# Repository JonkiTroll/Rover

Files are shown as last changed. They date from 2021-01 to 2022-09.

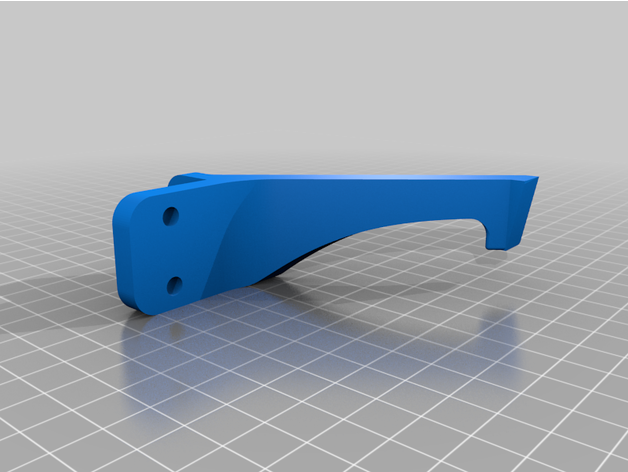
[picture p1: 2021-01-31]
Snow+Tank+from+RCTESTFLIGHT/images/Skid_Leg.png

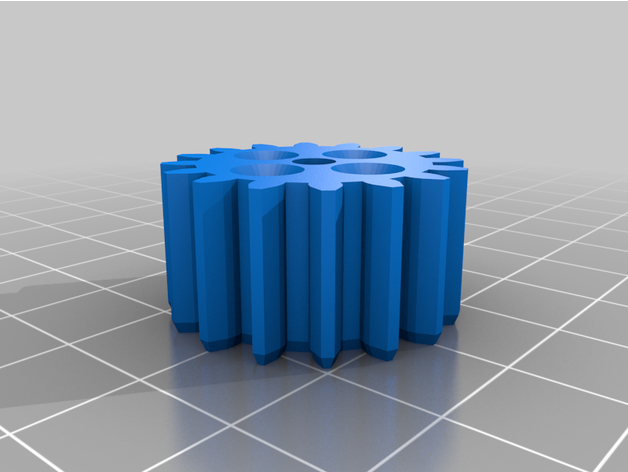
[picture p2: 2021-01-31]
Snow+Tank+from+RCTESTFLIGHT/images/Motor_Gear.png

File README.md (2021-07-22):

# Rover
Implementation of a rc tank. Based on rctestflight's design.

# Requirements
Python 3.8 on server and rover

pyttsx3 python library for RoverTTS.py. For Ubuntu linux, libespeak1 needs to be installed manually (sudo apt install libespeak1).

OpenCv2 for Video_server.py. 

# Utilities
GPS 	GY-NEO6MV2

IMU	Icm20948 (Pid controller)

Camera (Servo)  logitech webcam

Speakers

Temp, gas, barometer, humidity https://www.bosch-sensortec.com/products/environmental-sensors/gas-sensors/bme688/

Neopixels

Battery management (Fuel gauge) https://www.ti.com/product/BQ34110#product-details##description

expansion headers (Servos, analog pins)

Hall Effect sensors x2 (3390Q)

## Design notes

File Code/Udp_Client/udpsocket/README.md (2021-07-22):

# udpsocket

A udp socket created for Raspberry pi 4. UDPClient is the physical code set up on the raspberry and is designed to receive data from the controller.
It connects to an external server.
This project is based on CMake. The IDE used is CLion.

#Stuff to remember:

Uart Endmarkers.

ESC grounding.

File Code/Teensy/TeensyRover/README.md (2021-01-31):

# TeensyRover
A Teensy is used to generate a clean 1kHz signal to control the esc. Low en of the duty cycle is 13%, and high end 24%.
To compile and run the example, platformio is needed (https://docs.platformio.org/en/latest/what-is-platformio.html)

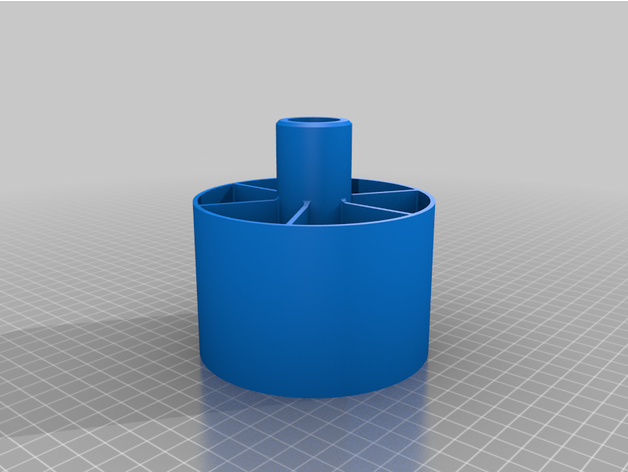
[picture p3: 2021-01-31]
Snow+Tank+from+RCTESTFLIGHT/images/103mm_Idler_Wheel.png

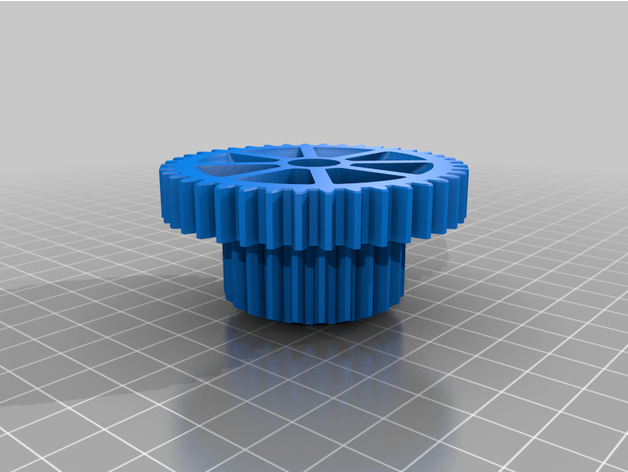
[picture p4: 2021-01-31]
Snow+Tank+from+RCTESTFLIGHT/images/40T_Output.png

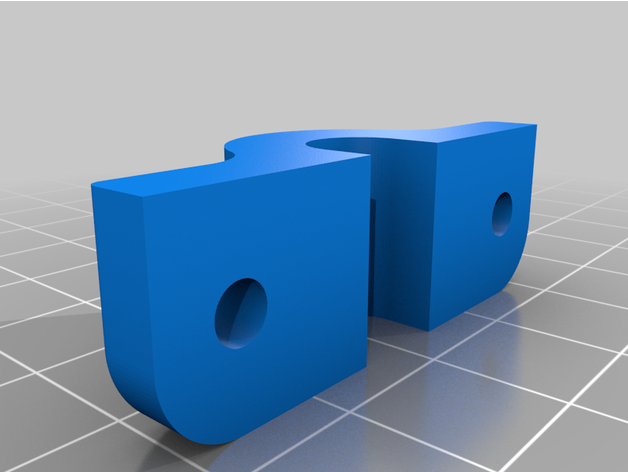
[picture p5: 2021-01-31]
Snow+Tank+from+RCTESTFLIGHT/images/8mm_Axel_Bracket.png

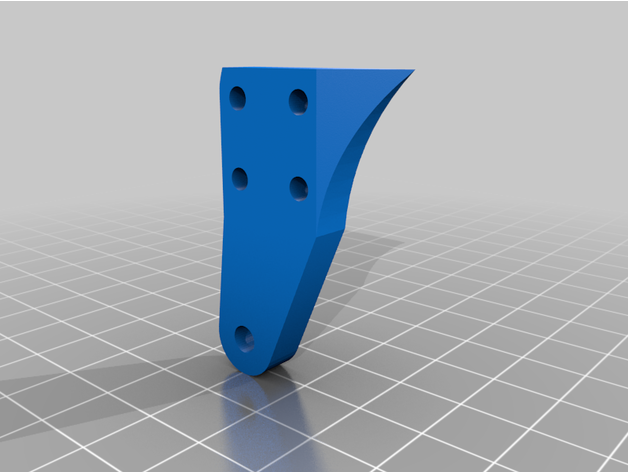
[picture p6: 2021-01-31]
Snow+Tank+from+RCTESTFLIGHT/images/Gearbox_Wrap_around_Plate.png

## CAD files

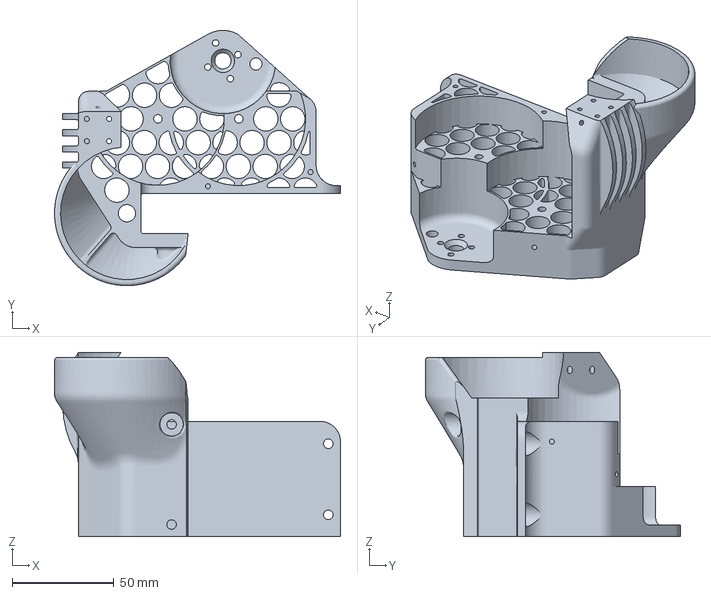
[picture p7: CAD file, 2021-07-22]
Snow+Tank+from+RCTESTFLIGHT/files/56_to_1_housing.3mf
140.7 x 125.6 x 90.8 mm

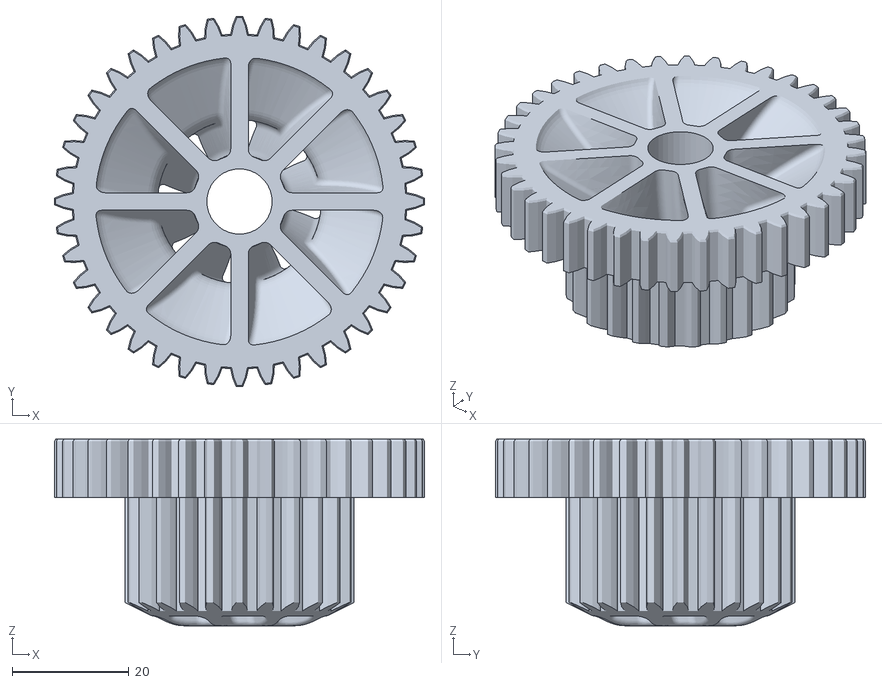
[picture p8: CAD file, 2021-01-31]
Snow+Tank+from+RCTESTFLIGHT/files/40T_Output.STL
63.5 x 63.5 x 32.0

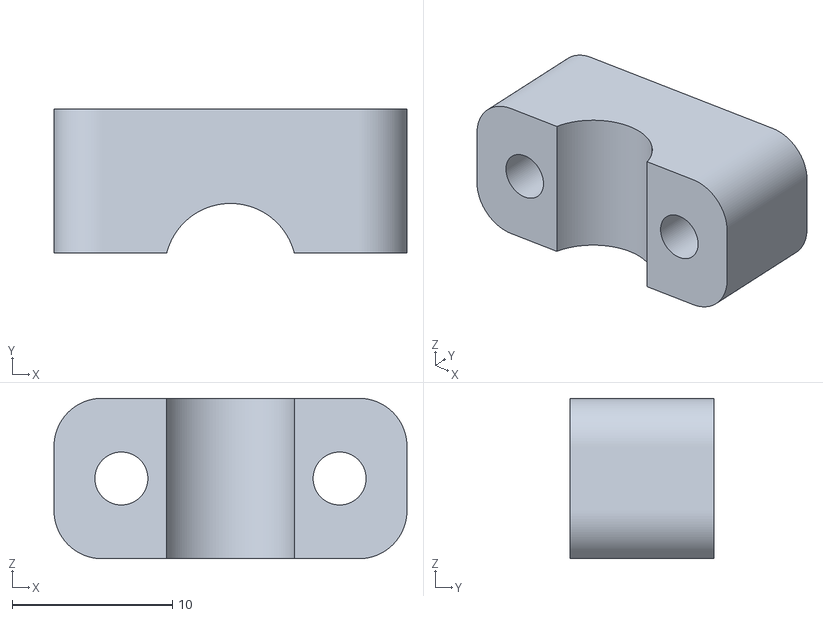
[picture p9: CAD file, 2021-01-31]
Snow+Tank+from+RCTESTFLIGHT/files/8mm_Tube_Clamp.stl
22.0 x 9.00 x 10.0

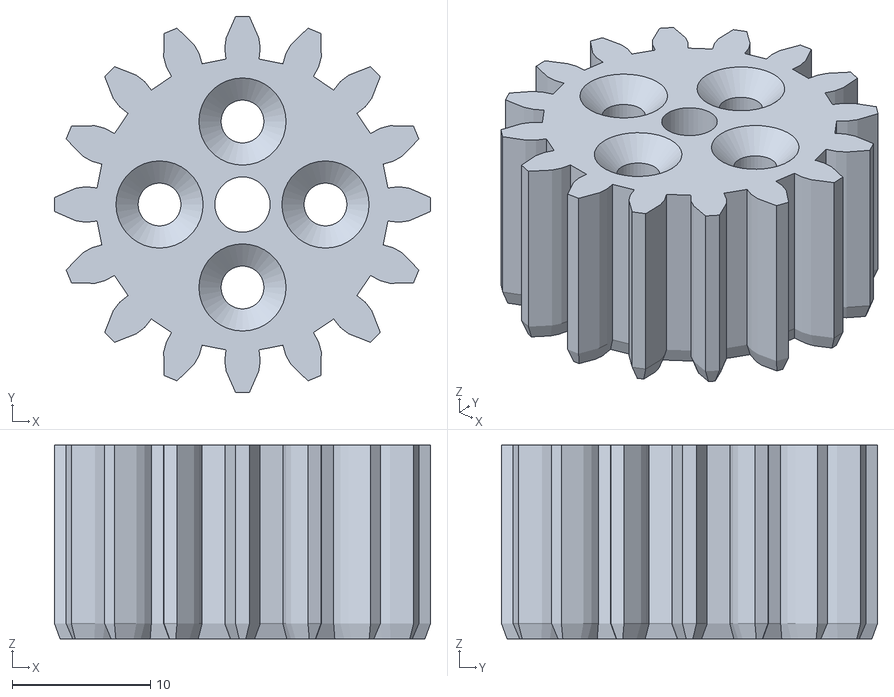
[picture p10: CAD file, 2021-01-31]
Snow+Tank+from+RCTESTFLIGHT/files/Motor_Gear.STL
27.2 x 27.2 x 14.0

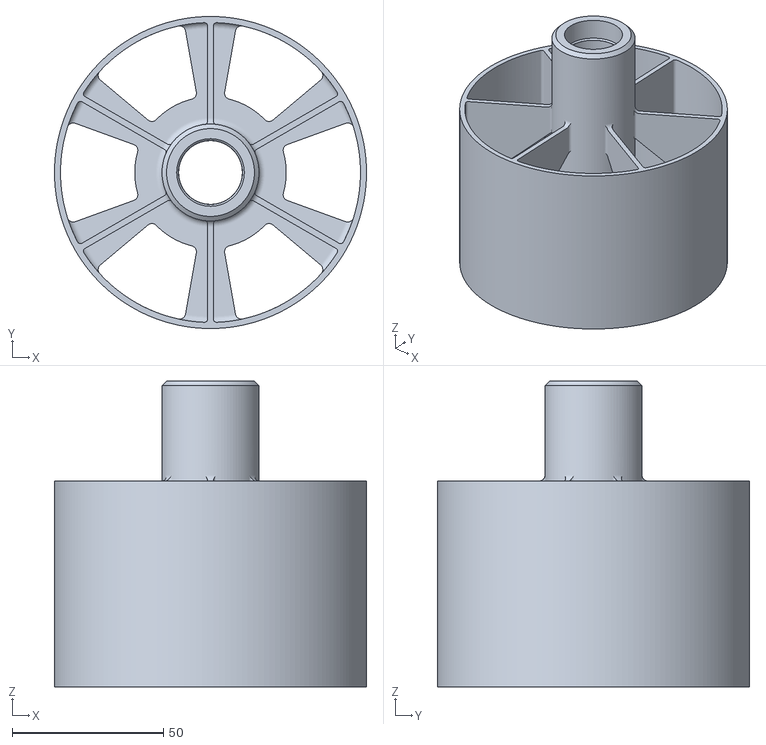
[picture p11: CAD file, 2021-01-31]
Snow+Tank+from+RCTESTFLIGHT/files/103mm_Idler_Wheel.stl
103.0 x 103.0 x 101.0

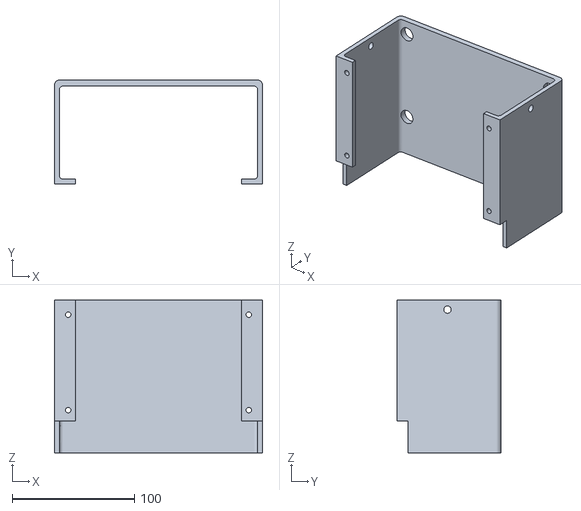
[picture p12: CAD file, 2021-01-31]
Snow+Tank+from+RCTESTFLIGHT/files/Simple_Top_Box.stl
170.0 x 85.0 x 125.0

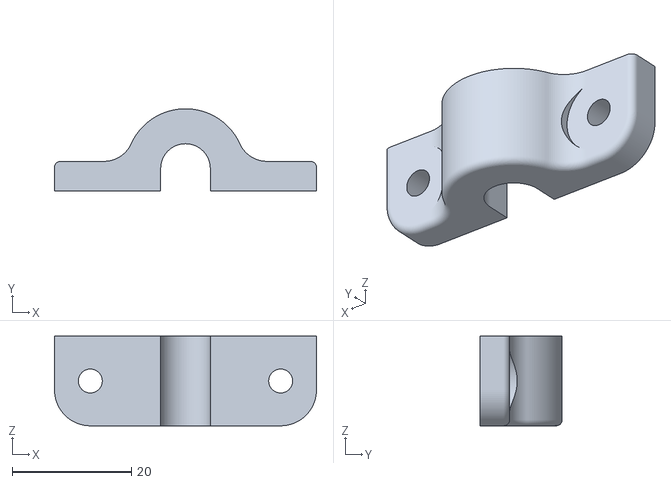
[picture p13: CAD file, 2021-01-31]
Snow+Tank+from+RCTESTFLIGHT/files/8mm_Axel_Bracket.stl
43.9 x 13.8 x 15.0

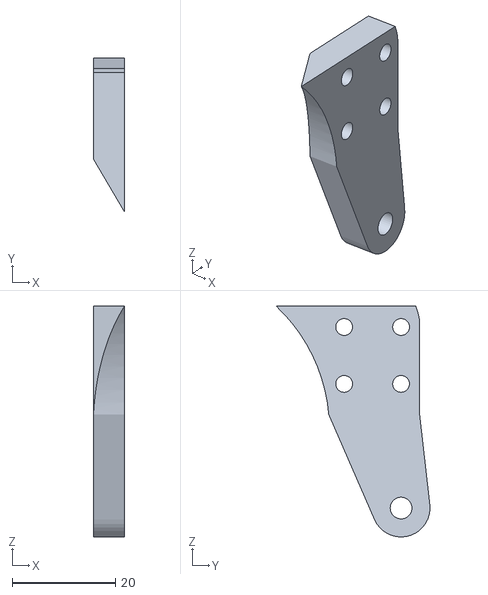
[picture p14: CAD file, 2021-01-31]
Snow+Tank+from+RCTESTFLIGHT/files/Gearbox_Wrap_around_Plate.STL
6.00 x 29.8 x 44.7

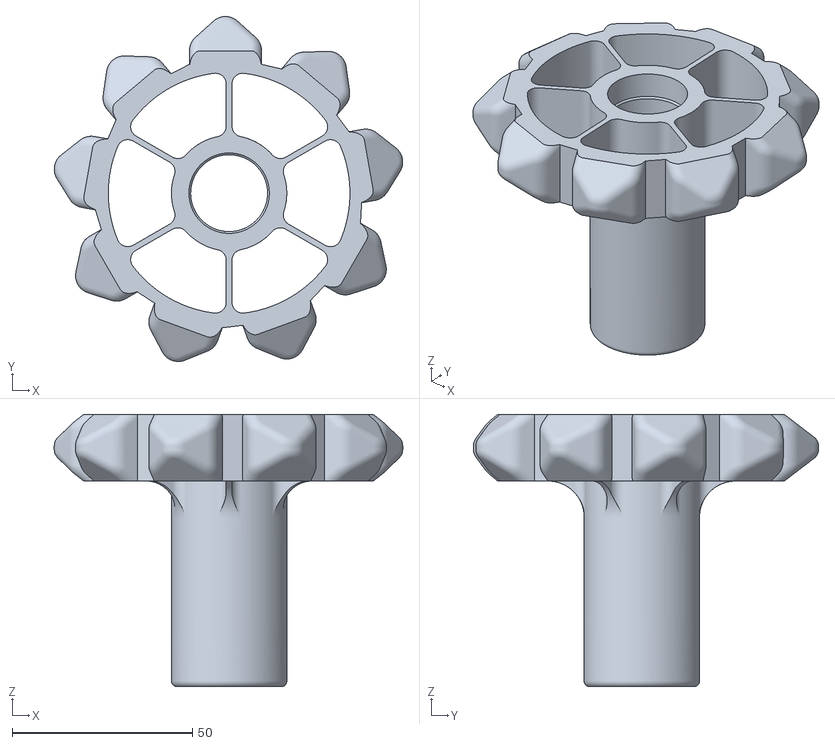
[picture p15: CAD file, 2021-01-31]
Snow+Tank+from+RCTESTFLIGHT/files/Snow_Pully_Rear.stl
96.6 x 95.7 x 75.5

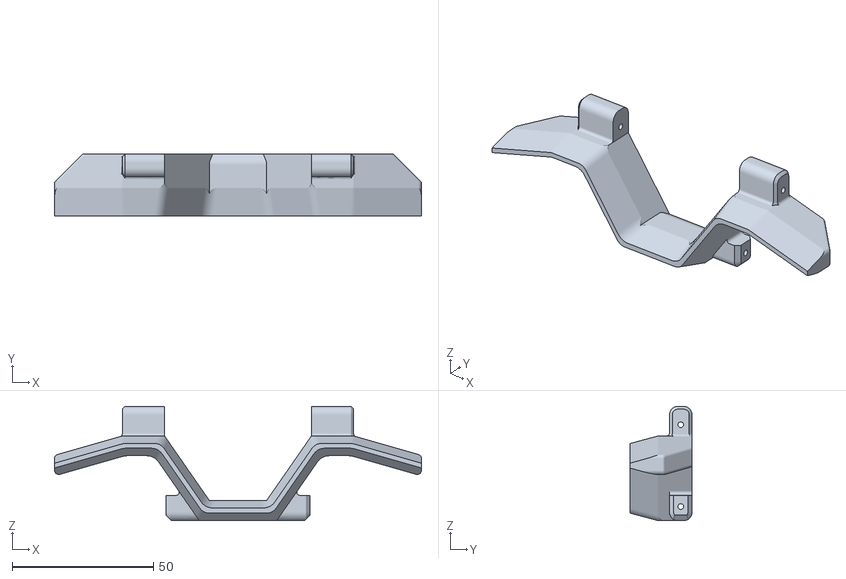
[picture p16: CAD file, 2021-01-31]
Snow+Tank+from+RCTESTFLIGHT/files/Snow_Track.STL
130.0 x 22.0 x 40.5

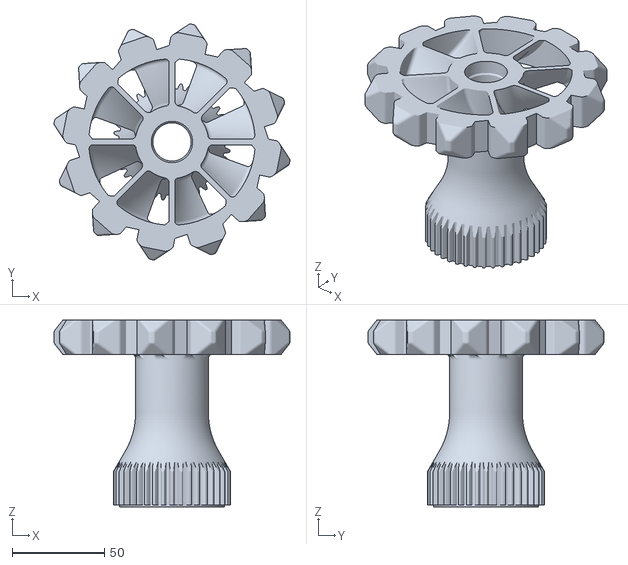
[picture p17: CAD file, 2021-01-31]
Snow+Tank+from+RCTESTFLIGHT/files/Snow_Wheel.stl
127.7 x 127.7 x 101.0

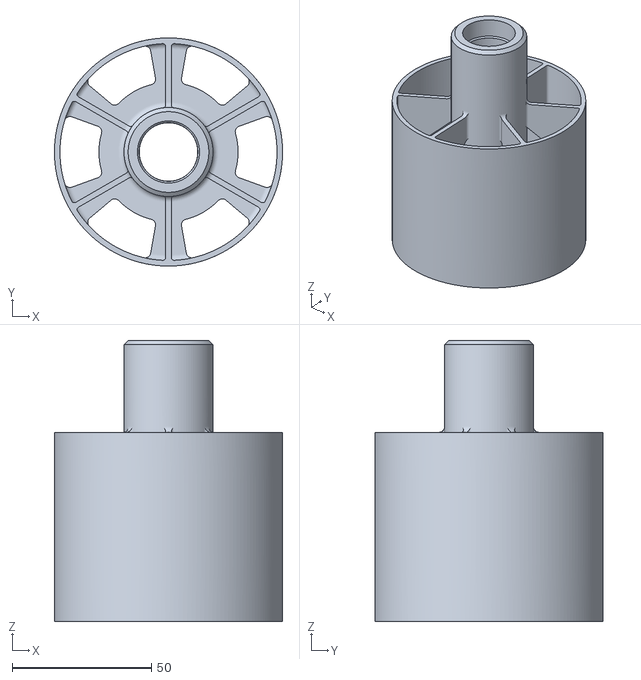
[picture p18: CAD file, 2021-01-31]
Snow+Tank+from+RCTESTFLIGHT/files/82mm_Idler_Wheel.stl
82.0 x 82.0 x 101.0

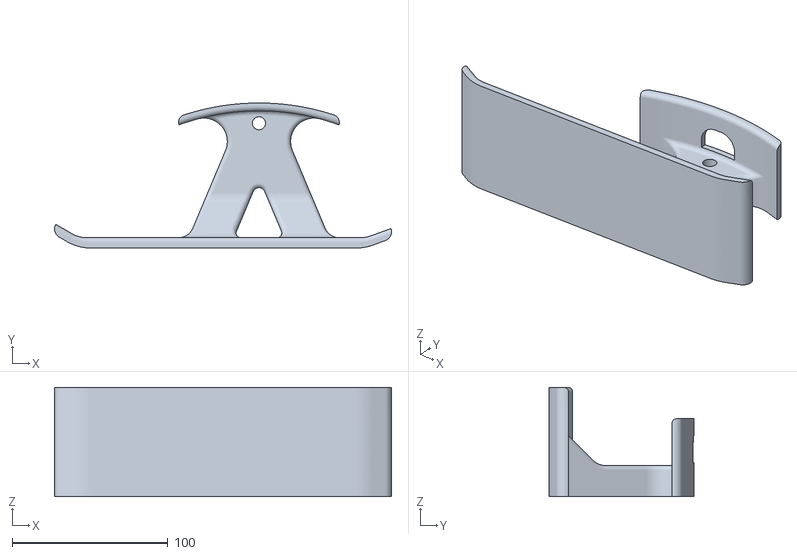
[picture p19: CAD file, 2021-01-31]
Snow+Tank+from+RCTESTFLIGHT/files/Skid.stl
216.1 x 93.0 x 70.0

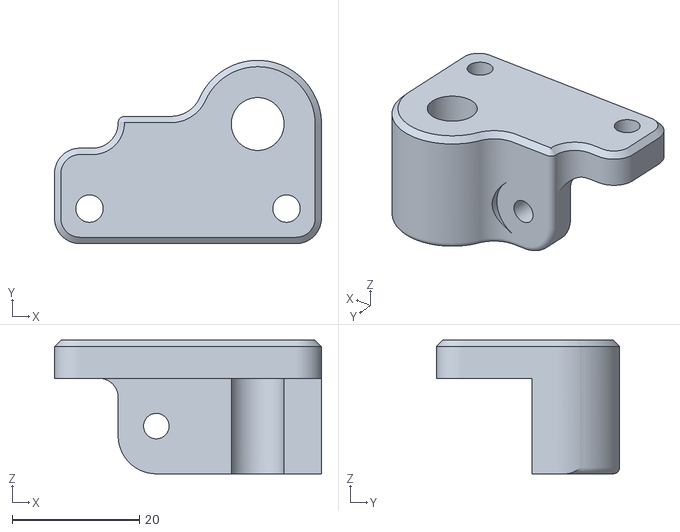
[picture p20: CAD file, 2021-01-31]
Snow+Tank+from+RCTESTFLIGHT/files/Corner_Axel_Holder_for_skids_only.stl
42.0 x 28.8 x 21.0

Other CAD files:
Snow+Tank+from+RCTESTFLIGHT/files/Skid_Leg.stl
Snow+Tank+from+RCTESTFLIGHT/files/Rear_Axel_Holder.STL
Snow+Tank+from+RCTESTFLIGHT/files/40T.STL
PCB/RaspberryPiHat_V2/TXB0108DQSR/Allegro/txb0108dqsr.psm
PCB/RaspberryPiHat_V2/TXB0108DQSR/DEHDL/txb0108dqsr/chips/chips.prt
Snow+Tank+from+RCTESTFLIGHT/files/56_to_1_housing.STL

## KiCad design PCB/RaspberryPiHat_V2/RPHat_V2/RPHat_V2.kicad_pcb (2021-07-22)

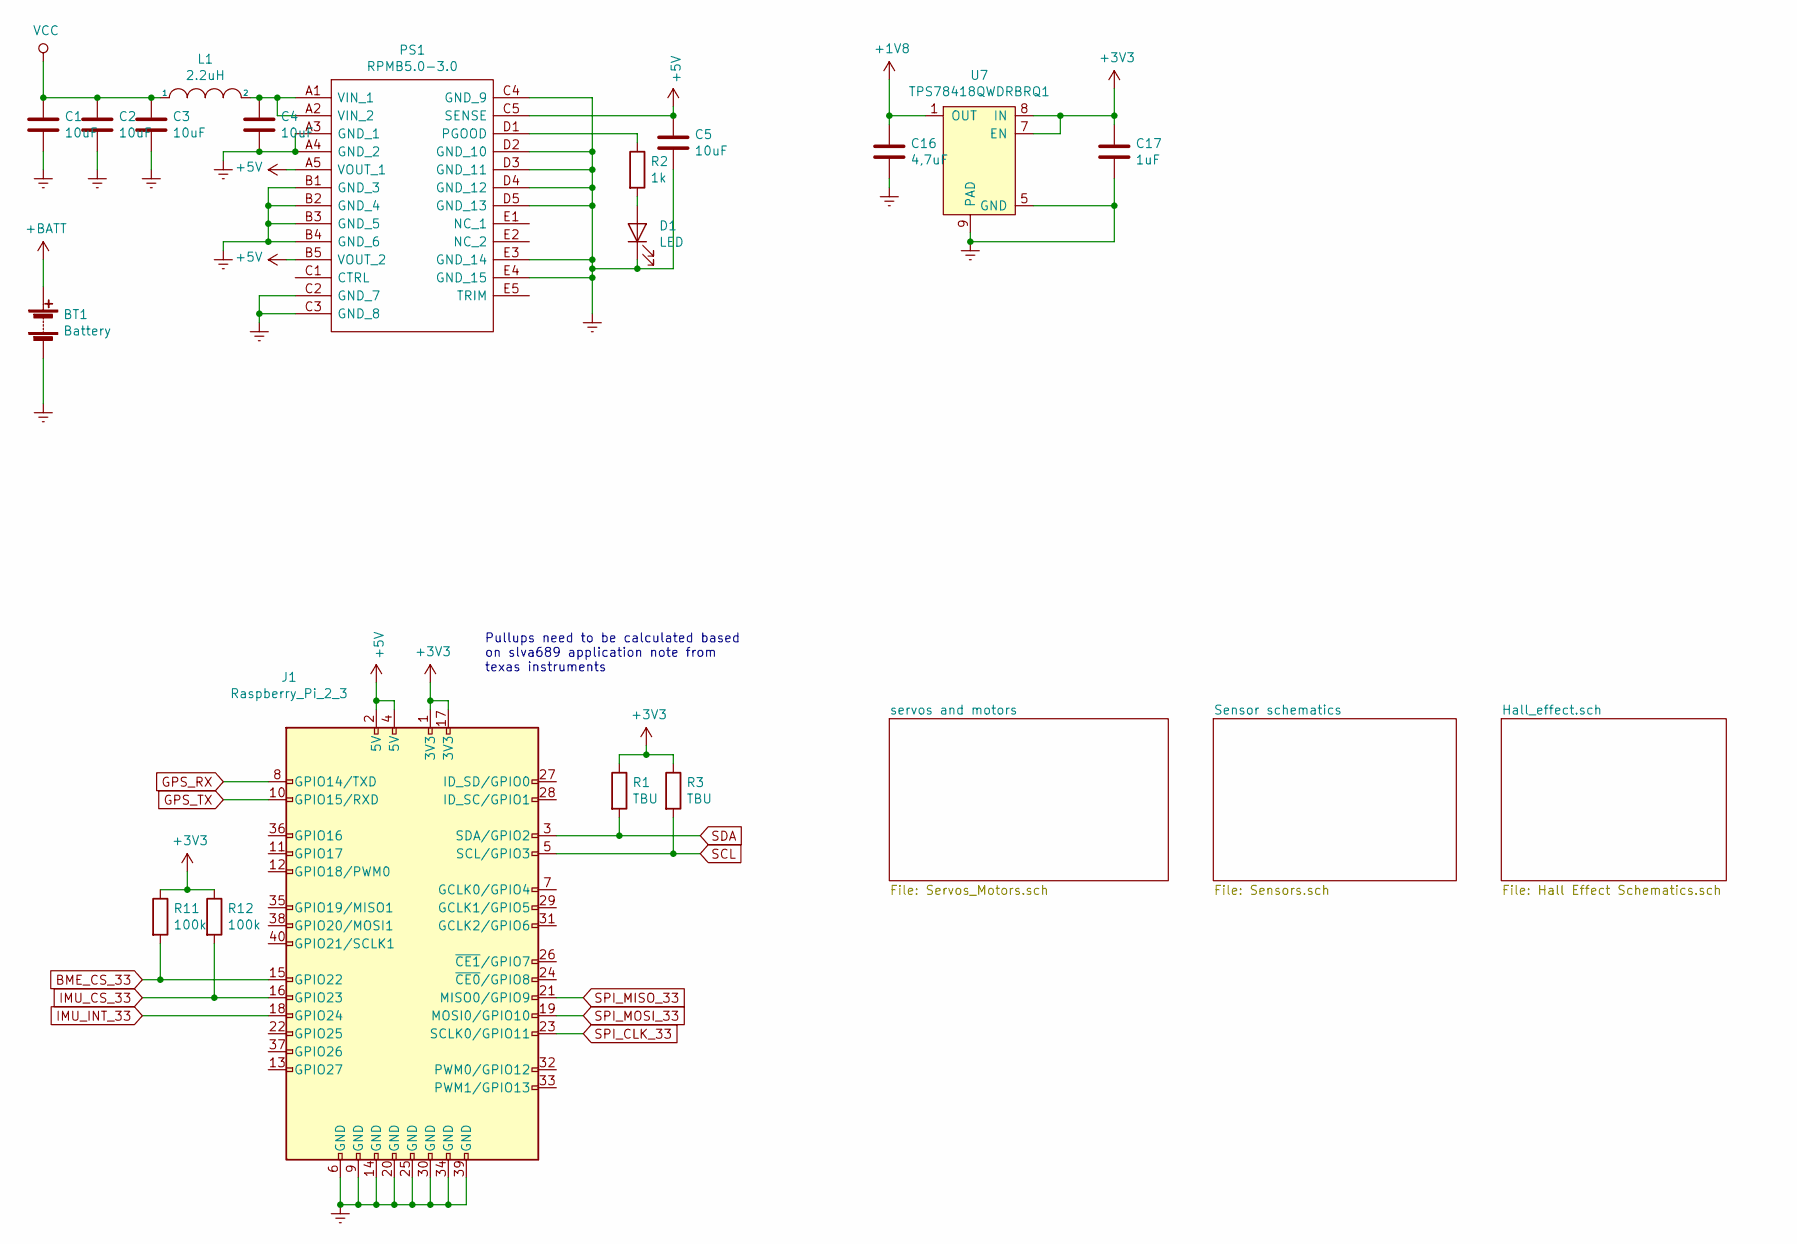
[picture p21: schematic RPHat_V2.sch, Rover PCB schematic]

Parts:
BT1: Battery; AMASS_XT60-M_1x02_P7.20mm_Vertical
C1, C2, C3, C4, C5: 10uF; C_1210_3225Metric_Pad1.33x2.70mm_HandSolder
C16: 4,7uF; C_0402_1005Metric_Pad0.74x0.62mm_HandSolder
C17: 1uF; C_0402_1005Metric_Pad0.74x0.62mm_HandSolder
D1: LED; R_0603_1608Metric_Pad0.98x0.95mm_HandSolder
J1: Raspberry_Pi_2_3; PinHeader_2x20_P2.54mm_Vertical
L1: 2.2uH; L_1008_2520Metric_Pad1.43x2.20mm_HandSolder
PS1: RPMB5.0-3.0; RPMB5030; Manufacturer_Part_Number RPMB5.0-3.0; Mouser Part Number 919-RPMB5.0-3.0
R1, R3: TBU; R_0603_1608Metric_Pad0.98x0.95mm_HandSolder
R2: 1k; R_0603_1608Metric_Pad0.98x0.95mm_HandSolder
R11, R12: 100k; R_0402_1005Metric_Pad0.72x0.64mm_HandSolder
U7: TPS78418QWDRBRQ1; Texas_S-PVSON-N8_ThermalVias

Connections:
+1V8: C16.1, U7.1 (OUT); also elsewhere on the board
+5V: C5.1, J1.2 (5V), J1.4 (5V), PS1.A5 (VOUT_1), PS1.B5 (VOUT_2), PS1.C5 (SENSE); also elsewhere on the board
+BATT: BT1.1 (+); also elsewhere on the board
BME_CS_33: J1.15 (GPIO22), R11.2; also elsewhere on the board
GNDREF: BT1.2 (-), C1.2, C2.2, C3.2, C4.2, C5.2, C16.2, C17.2, D1.1 (K), J1.6 (GND), J1.9 (GND), J1.14 (GND), J1.20 (GND), J1.25 (GND), J1.30 (GND), J1.34 (GND), J1.39 (GND), PS1.A3 (GND_1), PS1.A4 (GND_2), PS1.B1 (GND_3), PS1.B2 (GND_4), PS1.B3 (GND_5), PS1.B4 (GND_6), PS1.C2 (GND_7), PS1.C3 (GND_8), PS1.C4 (GND_9), PS1.D2 (GND_10), PS1.D3 (GND_11), PS1.D4 (GND_12), PS1.D5 (GND_13), PS1.E3 (GND_14), PS1.E4 (GND_15), U7.5 (GND), U7.9 (PAD); also elsewhere on the board
GPS_RX: J1.8 (GPIO14/TXD); also elsewhere on the board
GPS_TX: J1.10 (GPIO15/RXD); also elsewhere on the board
IMU_CS_33: J1.16 (GPIO23), R12.2; also elsewhere on the board
IMU_INT_33: J1.18 (GPIO24); also elsewhere on the board
unnamed: C4.1, L1.2, PS1.A1 (VIN_1), PS1.A2 (VIN_2)
unnamed: D1.2 (A), R2.2
unnamed: PS1.D1 (PGOOD), R2.1
SCL: J1.5 (SCL/GPIO3), R3.2; also elsewhere on the board
SDA: J1.3 (SDA/GPIO2), R1.2; also elsewhere on the board
SPI_CLK_33: J1.23 (SCLK0/GPIO11); also elsewhere on the board
SPI_MISO_33: J1.21 (MISO0/GPIO9); also elsewhere on the board
SPI_MOSI_33: J1.19 (MOSI0/GPIO10); also elsewhere on the board
VCC: C1.1, C2.1, C3.1, L1.1; also elsewhere on the board

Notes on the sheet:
Pullups need to be calculated based on slva689 application note from texas instruments

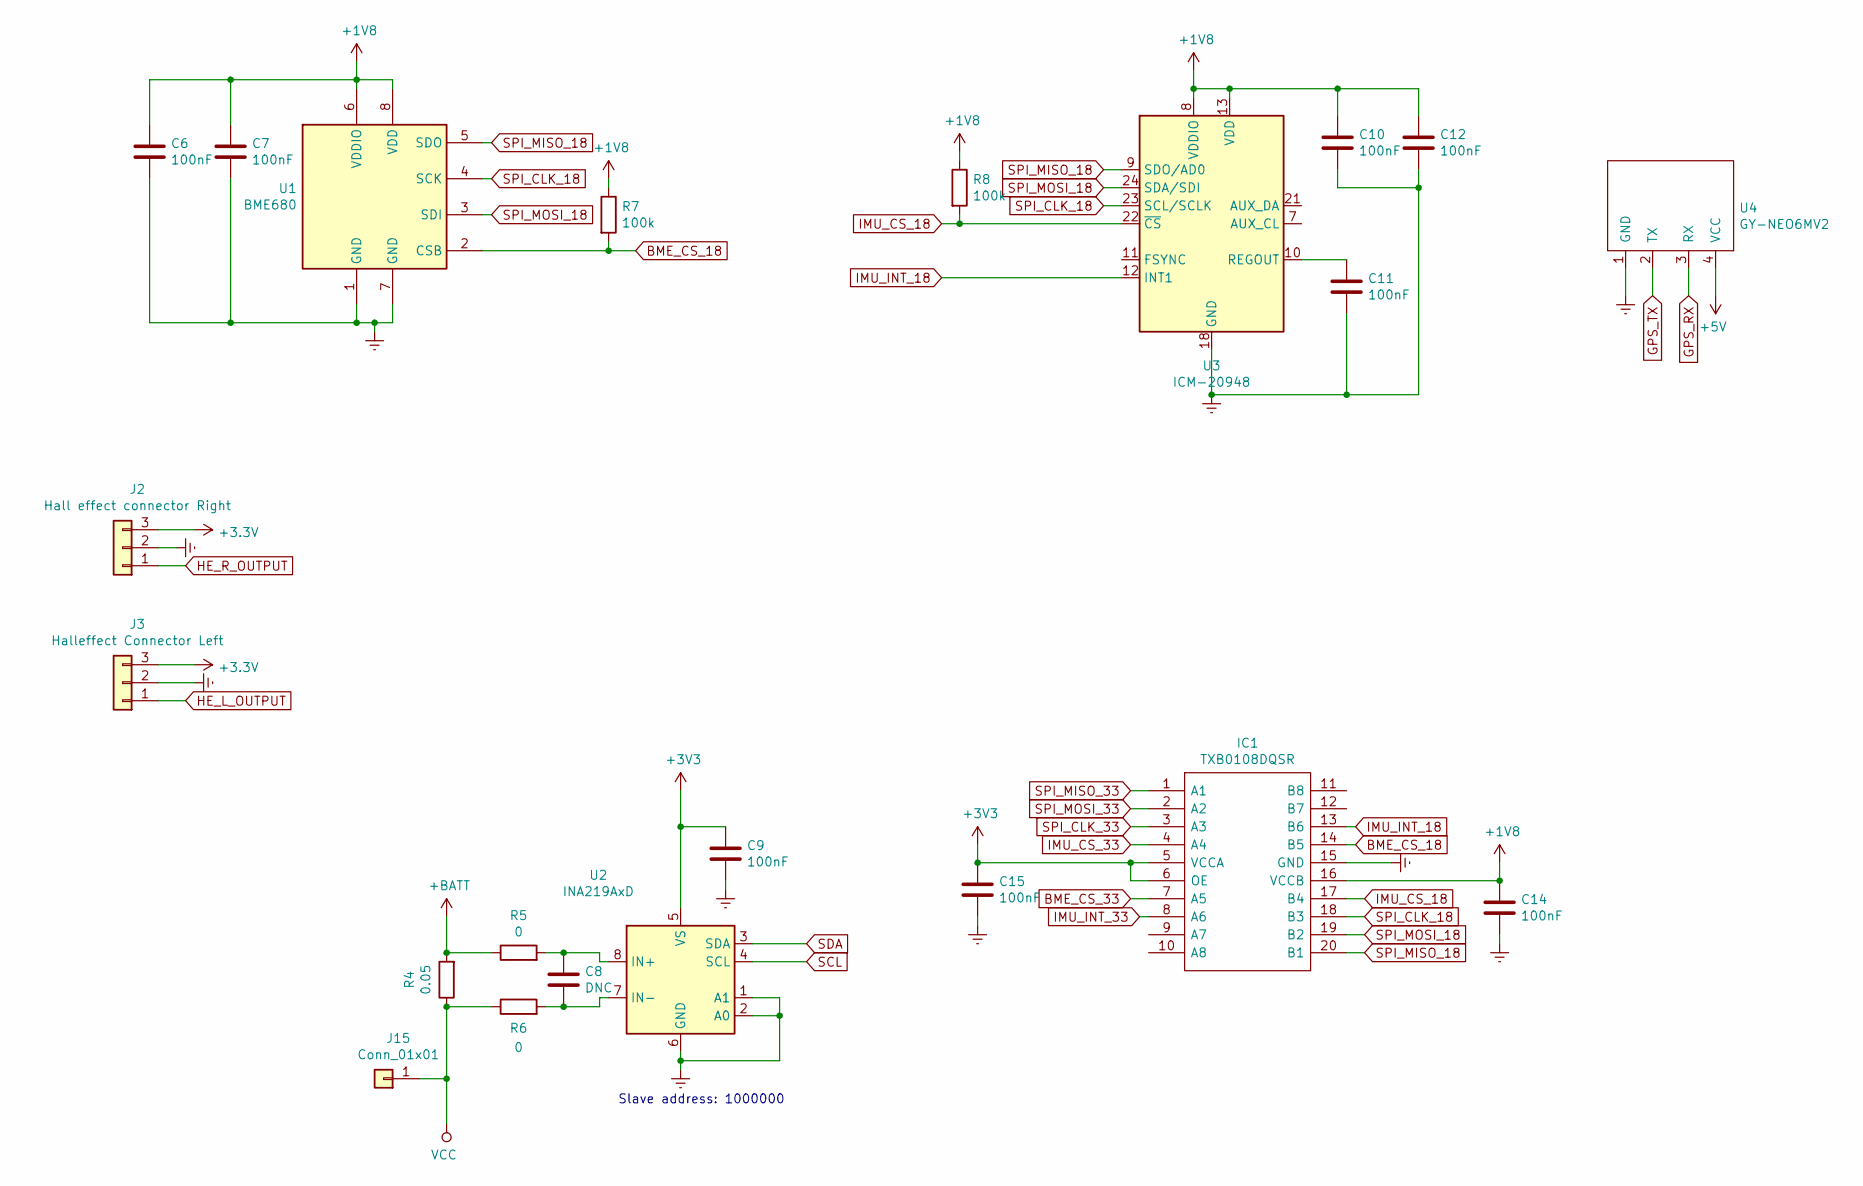
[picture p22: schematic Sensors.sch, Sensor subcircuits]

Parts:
C6, C7, C10, C11, C12, C14, C15: 100nF; C_0402_1005Metric_Pad0.74x0.62mm_HandSolder
C8: DNC; C_0603_1608Metric_Pad1.08x0.95mm_HandSolder
C9: 100nF; C_0603_1608Metric_Pad1.08x0.95mm_HandSolder
IC1: TXB0108DQSR; Manufacturer_Part_Number TXB0108DQSR; Mouser Part Number 595-TXB0108DQSR
J2: Hall effect connector Right; JST_EH_B3B-EH-A_1x03_P2.50mm_Vertical
J3: Halleffect Connector Left; JST_EH_B3B-EH-A_1x03_P2.50mm_Vertical
J15: Conn_01x01; Pin_D1.3mm_L11.0mm
R4: 0.05; CSS2H-3920
R5, R6: 0; R_0603_1608Metric_Pad0.98x0.95mm_HandSolder
R7, R8: 100k; R_0402_1005Metric_Pad0.72x0.64mm_HandSolder
U1: BME680; Bosch_LGA-8_3x3mm_P0.8mm_ClockwisePinNumbering
U2: INA219AxD; SOIC-8_3.9x4.9mm_P1.27mm
U3: ICM-20948; InvenSense_QFN-24_3x3mm_P0.4mm
U4: GY-NEO6MV2

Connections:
+1V8: C6.1, C7.1, C10.1, C12.1, C14.1, IC1.16 (VCCB), R7.1, R8.1, U1.6 (VDDIO), U1.8 (VDD), U3.8 (VDDIO), U3.13 (VDD); also elsewhere on the board
+5V: U4.4 (VCC); also elsewhere on the board
+BATT: R4.2, R5.1; also elsewhere on the board
BME_CS_18: IC1.14 (B5), R7.2, U1.2 (CSB)
BME_CS_33: IC1.7 (A5); also elsewhere on the board
GNDREF: C6.2, C7.2, C9.2, C10.2, C11.2, C12.2, C14.2, C15.2, IC1.15 (GND), J2.2, J3.2, U1.1 (GND), U1.7 (GND), U2.1 (A1), U2.2 (A0), U2.6 (GND), U3.18 (GND), U3.20 (GND), U4.1 (GND); also elsewhere on the board
GPS_RX: U4.3 (RX); also elsewhere on the board
GPS_TX: U4.2 (TX); also elsewhere on the board
HE_L_OUTPUT: J3.1; also elsewhere on the board
HE_R_OUTPUT: J2.1; also elsewhere on the board
IMU_CS_18: IC1.17 (B4), R8.2, U3.22 (~CS)
IMU_CS_33: IC1.4 (A4); also elsewhere on the board
IMU_INT_18: IC1.13 (B6), U3.12 (INT1)
IMU_INT_33: IC1.8 (A6); also elsewhere on the board
unnamed: C8.1, R5.2, U2.8 (IN+)
unnamed: C8.2, R6.2, U2.7 (IN-)
unnamed: C11.1, U3.10 (REGOUT)
SCL: U2.4 (SCL); also elsewhere on the board
SDA: U2.3 (SDA); also elsewhere on the board
SPI_CLK_18: IC1.18 (B3), U1.4 (SCK), U3.23 (SCL/SCLK)
SPI_CLK_33: IC1.3 (A3); also elsewhere on the board
SPI_MISO_18: IC1.20 (B1), U1.5 (SDO), U3.9 (SDO/AD0)
SPI_MISO_33: IC1.1 (A1); also elsewhere on the board
SPI_MOSI_18: IC1.19 (B2), U1.3 (SDI), U3.24 (SDA/SDI)
SPI_MOSI_33: IC1.2 (A2); also elsewhere on the board
VCC: J15.1, R4.1, R6.1; also elsewhere on the board

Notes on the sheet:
Slave address: 1000000

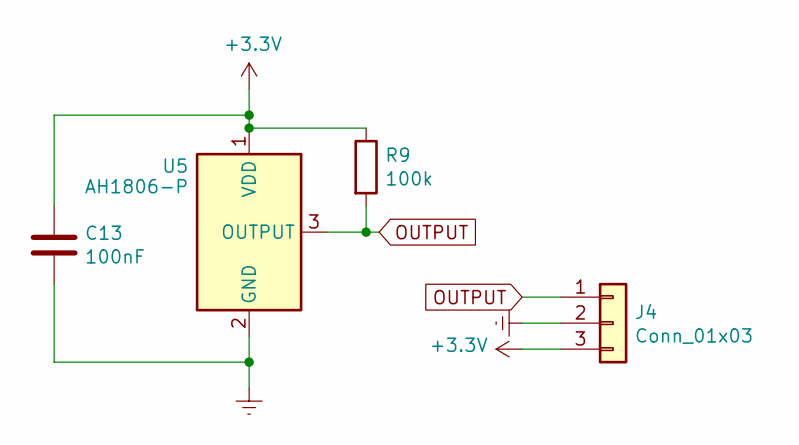
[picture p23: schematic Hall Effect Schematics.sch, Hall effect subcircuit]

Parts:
C13: 100nF; C_0603_1608Metric_Pad1.08x0.95mm_HandSolder
J4: Conn_01x03; PinHeader_1x03_P2.54mm_Vertical
R9: 100k; R_0603_1608Metric_Pad0.98x0.95mm_HandSolder
U5: AH1806-P; PinHeader_1x03_P2.54mm_Vertical

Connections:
unnamed: C13.1, J4.2, U5.2 (GND)
unnamed: C13.2, J4.3, R9.1, U5.1 (VDD)
unnamed: J4.1, R9.2, U5.3 (OUTPUT)

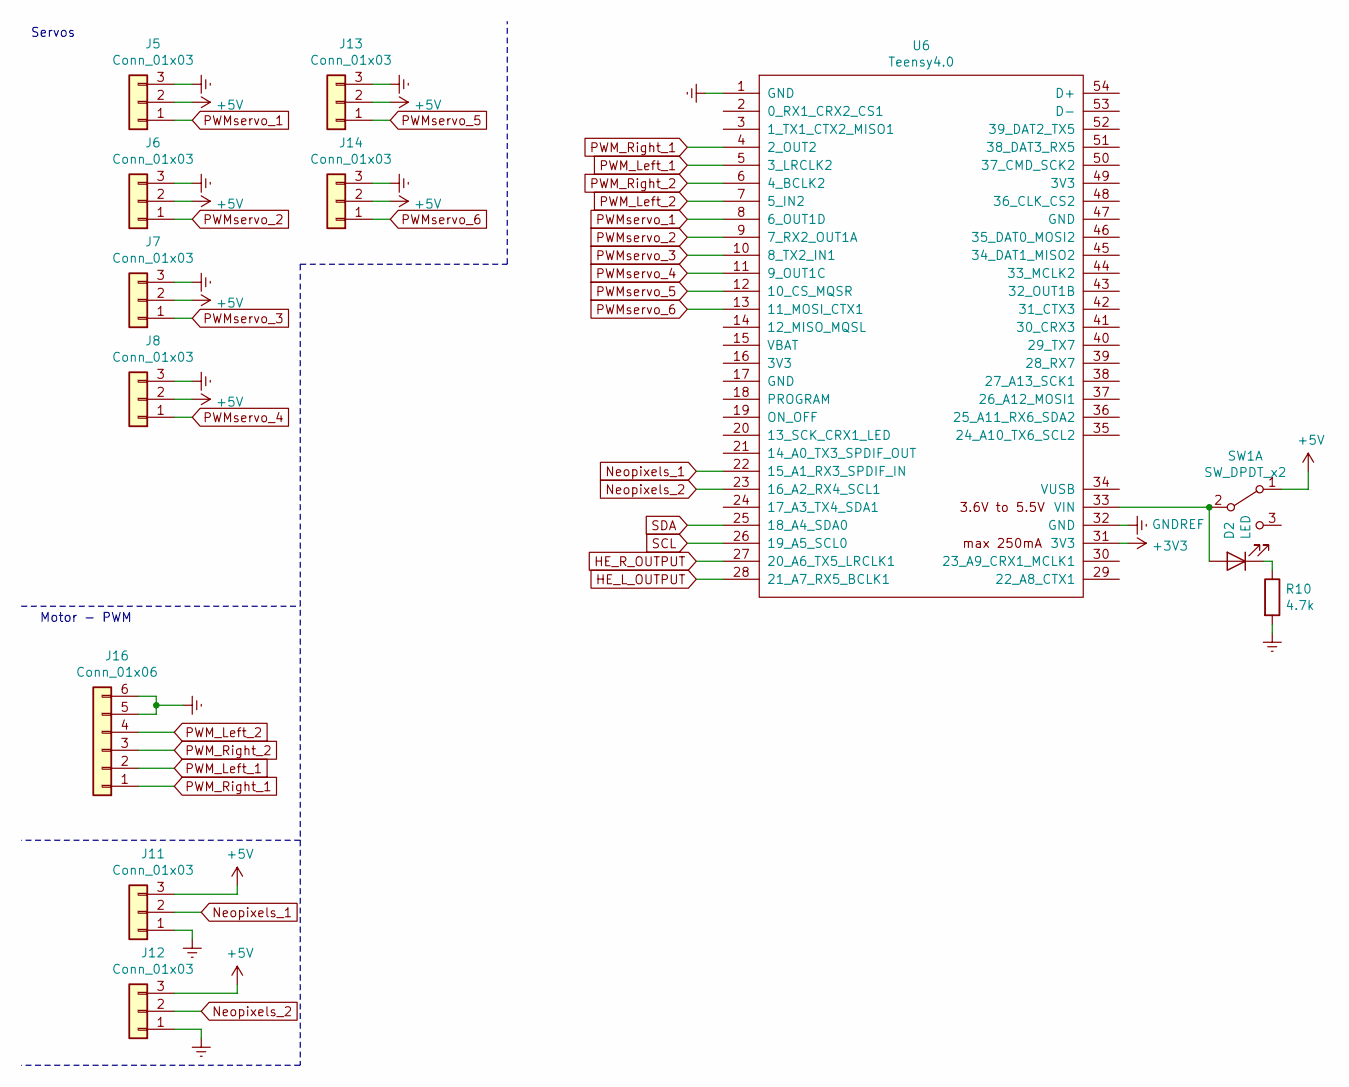
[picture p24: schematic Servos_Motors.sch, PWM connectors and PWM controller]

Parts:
D2: LED; R_0603_1608Metric_Pad0.98x0.95mm_HandSolder
J5, J6, J7, J8, J11, J12, J13, J14: Conn_01x03; JST_EH_B3B-EH-A_1x03_P2.50mm_Vertical
J16: Conn_01x06; JST_EH_B6B-EH-A_1x06_P2.50mm_Vertical
R10: 4.7k; R_0603_1608Metric_Pad0.98x0.95mm_HandSolder
SW1: SW_DPDT_x2; PinHeader_1x03_P2.54mm_Vertical
U6: Teensy4.0; Teensy40

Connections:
+5V: J5.2, J6.2, J7.2, J8.2, J11.3, J12.3, J13.2, J14.2, SW1.1 (A); also elsewhere on the board
GNDREF: J5.3, J6.3, J7.3, J8.3, J11.1, J12.1, J13.3, J14.3, J16.5, J16.6, R10.2, U6.1 (GND), U6.32 (GND); also elsewhere on the board
HE_L_OUTPUT: U6.28 (21_A7_RX5_BCLK1); also elsewhere on the board
HE_R_OUTPUT: U6.27 (20_A6_TX5_LRCLK1); also elsewhere on the board
Neopixels_1: J11.2, U6.22 (15_A1_RX3_SPDIF_IN)
Neopixels_2: J12.2, U6.23 (16_A2_RX4_SCL1)
unnamed: D2.1 (K), R10.1
unnamed: D2.2 (A), SW1.2 (B), U6.33 (VIN)
PWM_Left_1: J16.2, U6.5 (3_LRCLK2)
PWM_Left_2: J16.4, U6.7 (5_IN2)
PWM_Right_1: J16.1, U6.4 (2_OUT2)
PWM_Right_2: J16.3, U6.6 (4_BCLK2)
PWMservo_1: J5.1, U6.8 (6_OUT1D)
PWMservo_2: J6.1, U6.9 (7_RX2_OUT1A)
PWMservo_3: J7.1, U6.10 (8_TX2_IN1)
PWMservo_4: J8.1, U6.11 (9_OUT1C)
PWMservo_5: J13.1, U6.12 (10_CS_MQSR)
PWMservo_6: J14.1, U6.13 (11_MOSI_CTX1)
SCL: U6.26 (19_A5_SCL0); also elsewhere on the board
SDA: U6.25 (18_A4_SDA0); also elsewhere on the board

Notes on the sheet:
Servos
Motor - PWM

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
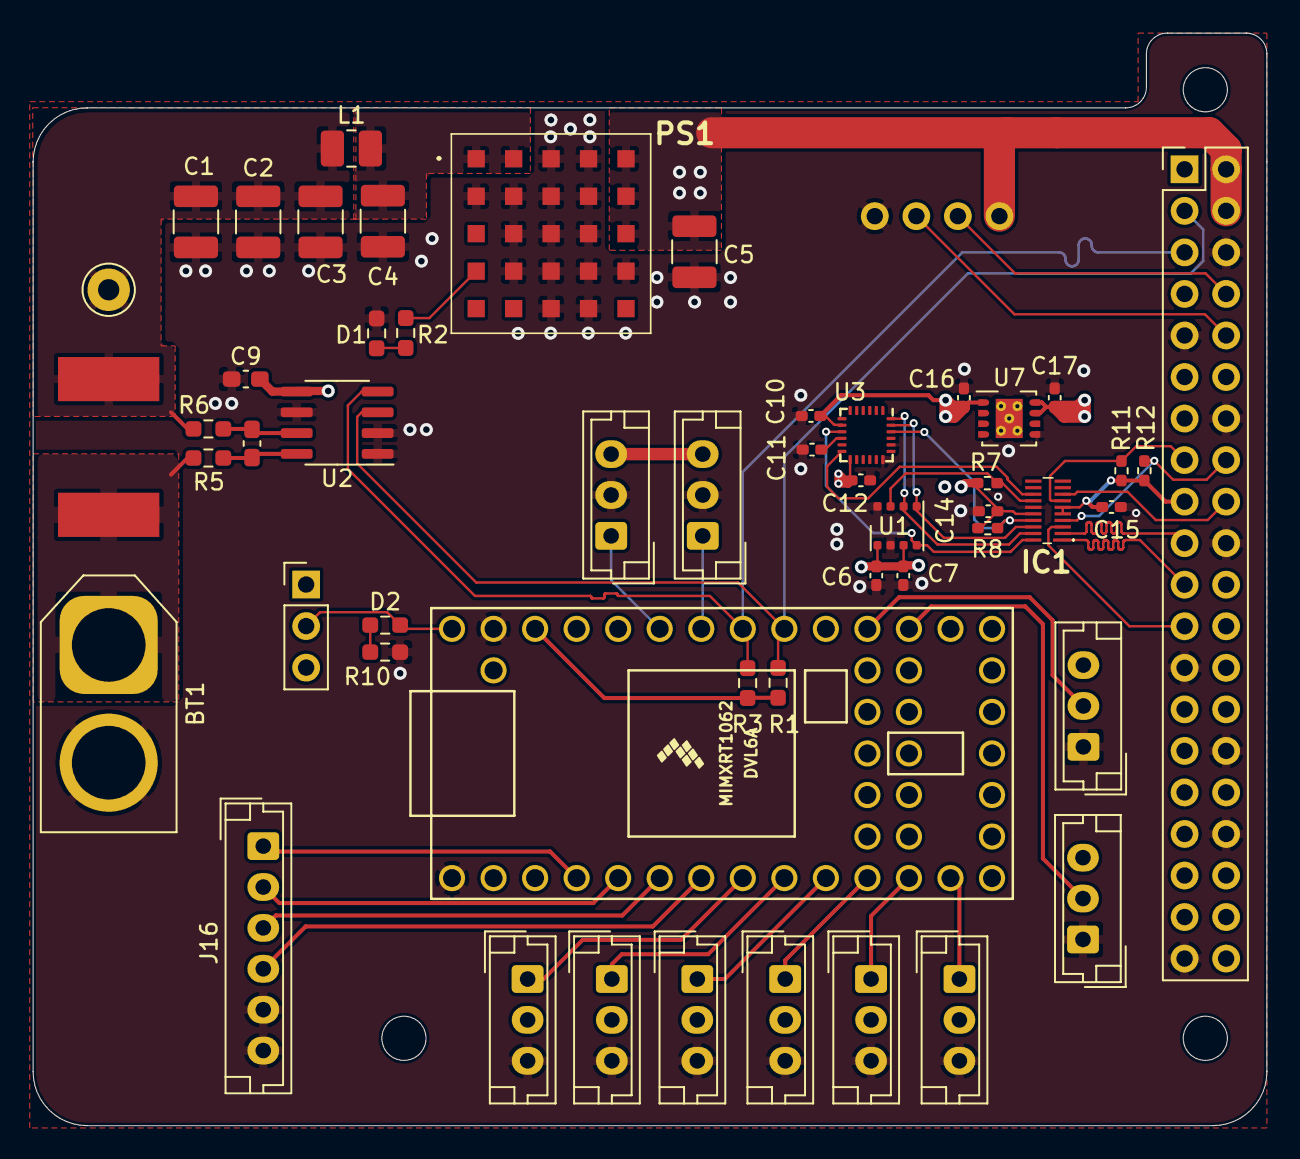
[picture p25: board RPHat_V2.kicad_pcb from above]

Board: 4 copper layers, 75.4 x 66.8 mm, 53 parts (0 on the bottom side), 44 nets.

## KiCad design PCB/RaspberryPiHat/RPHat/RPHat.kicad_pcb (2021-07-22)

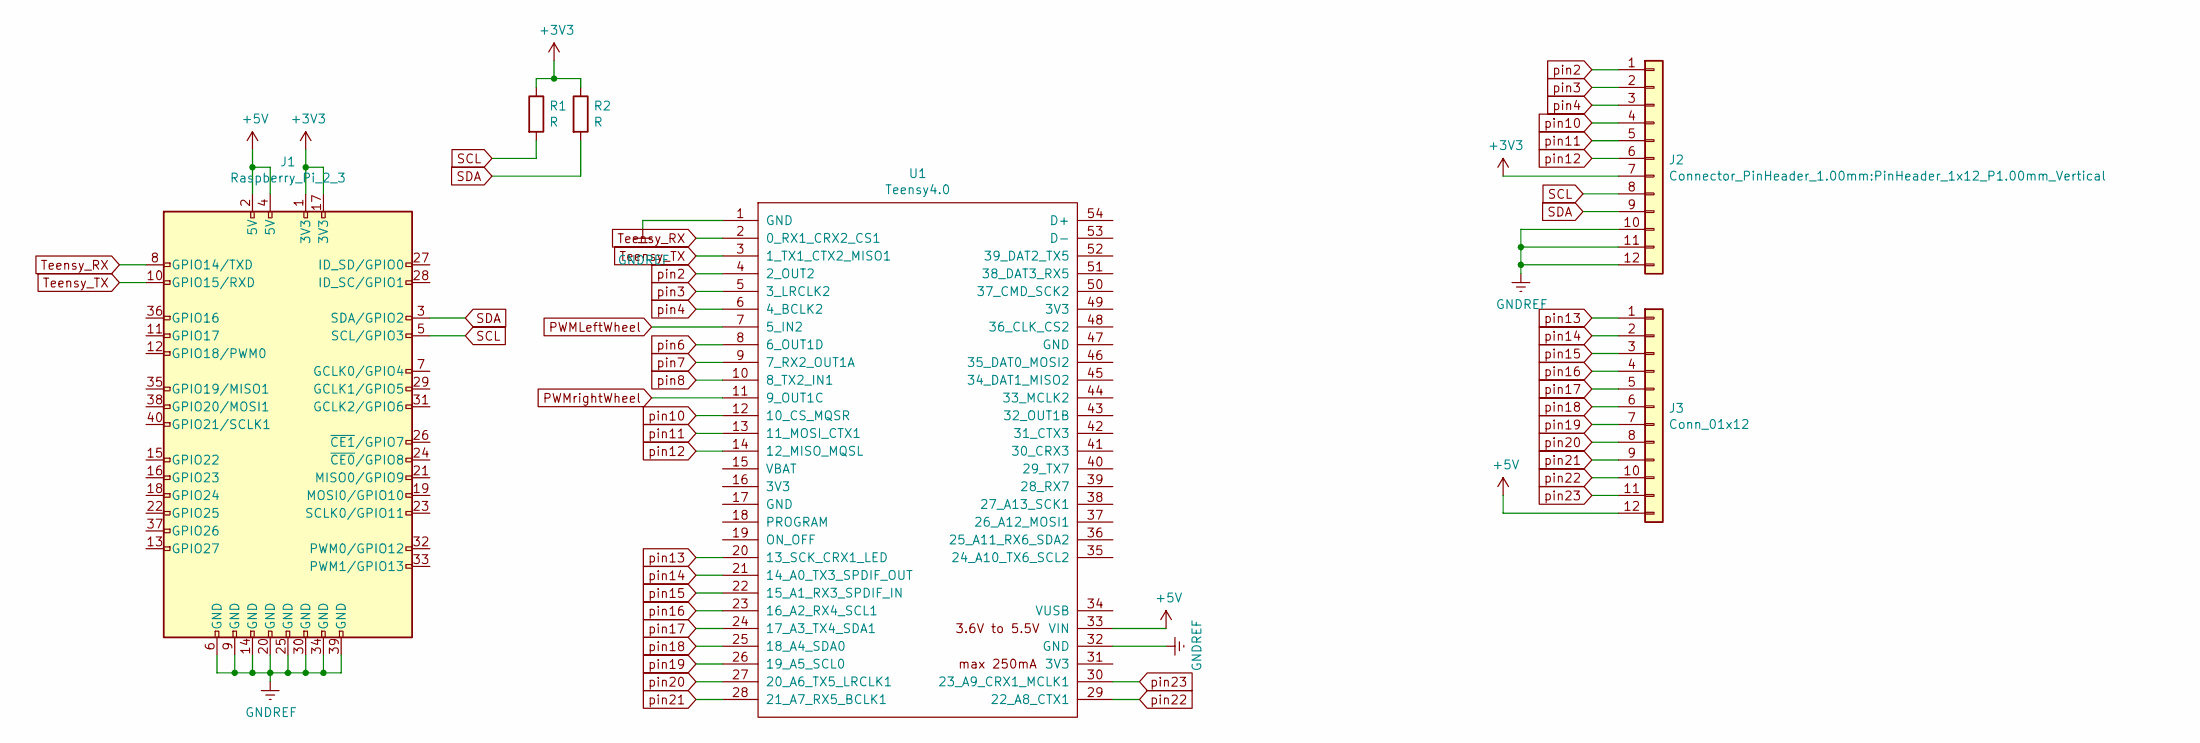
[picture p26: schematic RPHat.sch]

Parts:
J1: Raspberry_Pi_2_3; PinSocket_2x20_P2.54mm_Vertical
J2: Connector_PinHeader_1.00mm:PinHeader_1x12_P1.00mm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; PinHeader_1x12_P2.54mm_Vertical
J3: Conn_01x12; PinHeader_1x12_P2.54mm_Vertical
R1, R2: R; R_Box_L13.0mm_W4.0mm_P9.00mm
U1: Teensy4.0; Teensy40

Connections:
+3V3: J1.1 (3V3), J1.17 (3V3), J2.7, R1.1, R2.1
+5V: J1.2 (5V), J1.4 (5V), J3.12, U1.33 (VIN)
GNDREF: J1.6 (GND), J1.9 (GND), J1.14 (GND), J1.20 (GND), J1.25 (GND), J1.30 (GND), J1.34 (GND), J1.39 (GND), J2.10, J2.11, J2.12, U1.1 (GND), U1.32 (GND)
PWMLeftWheel: U1.7 (5_IN2)
PWMrightWheel: U1.11 (9_OUT1C)
SCL: J1.5 (SCL/GPIO3), J2.8, R1.2
SDA: J1.3 (SDA/GPIO2), J2.9, R2.2
Teensy_RX: J1.8 (GPIO14/TXD), U1.2 (0_RX1_CRX2_CS1)
Teensy_TX: J1.10 (GPIO15/RXD), U1.3 (1_TX1_CTX2_MISO1)
pin2: J2.1, U1.4 (2_OUT2)
pin3: J2.2, U1.5 (3_LRCLK2)
pin4: J2.3, U1.6 (4_BCLK2)
pin6: U1.8 (6_OUT1D)
pin7: U1.9 (7_RX2_OUT1A)
pin8: U1.10 (8_TX2_IN1)
pin10: J2.4, U1.12 (10_CS_MQSR)
pin11: J2.5, U1.13 (11_MOSI_CTX1)
pin12: J2.6, U1.14 (12_MISO_MQSL)
pin13: J3.1, U1.20 (13_SCK_CRX1_LED)
pin14: J3.2, U1.21 (14_A0_TX3_SPDIF_OUT)
pin15: J3.3, U1.22 (15_A1_RX3_SPDIF_IN)
pin16: J3.4, U1.23 (16_A2_RX4_SCL1)
pin17: J3.5, U1.24 (17_A3_TX4_SDA1)
pin18: J3.6, U1.25 (18_A4_SDA0)
pin19: J3.7, U1.26 (19_A5_SCL0)
pin20: J3.8, U1.27 (20_A6_TX5_LRCLK1)
pin21: J3.9, U1.28 (21_A7_RX5_BCLK1)
pin22: J3.10, U1.29 (22_A8_CTX1)
pin23: J3.11, U1.30 (23_A9_CRX1_MCLK1)

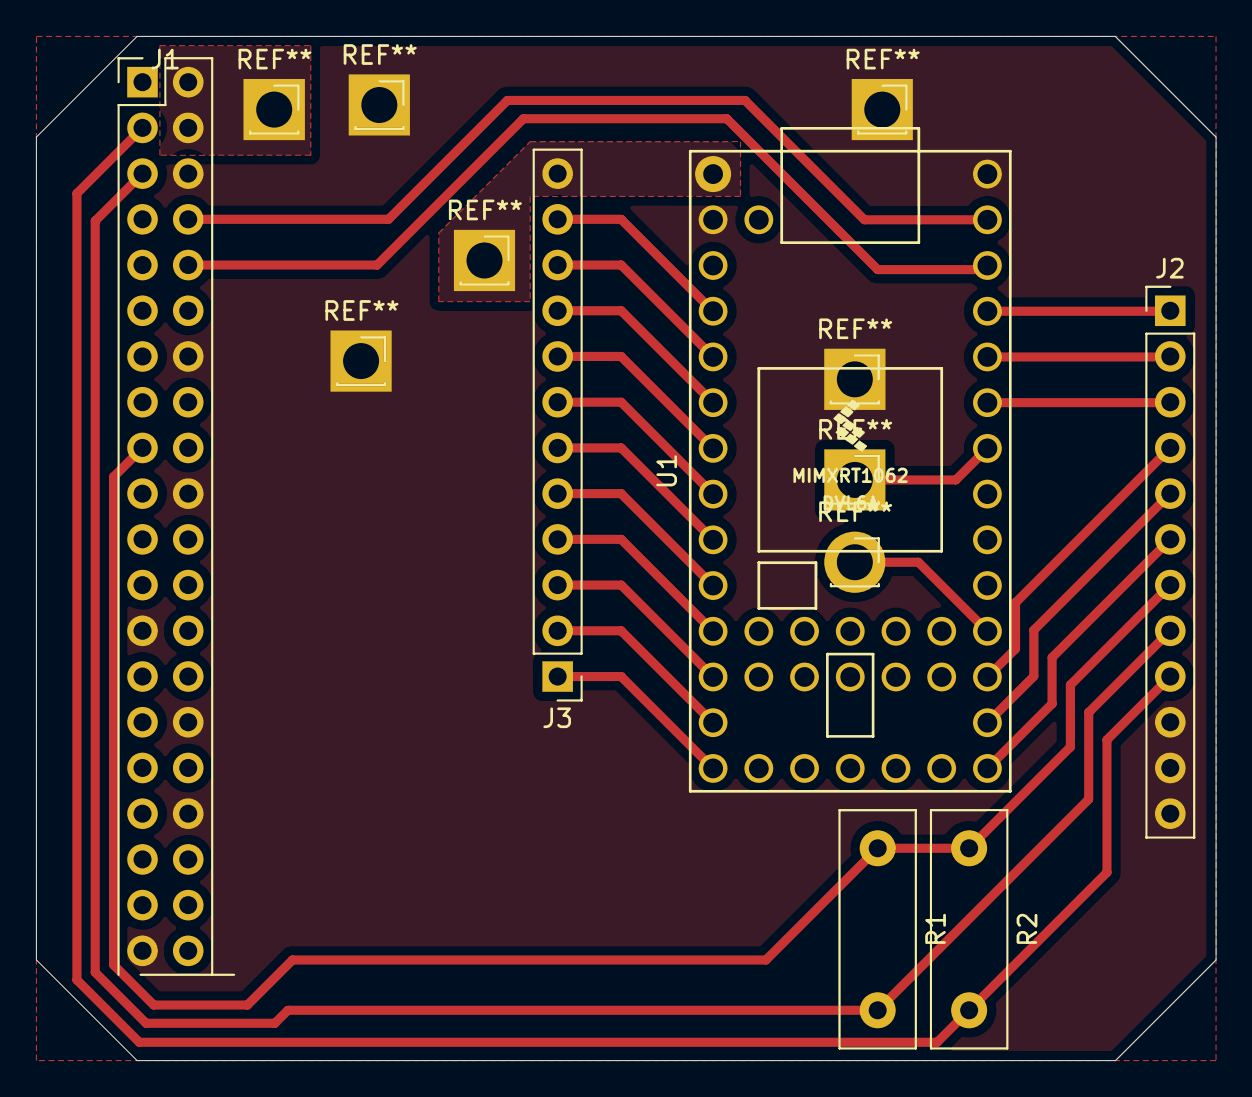
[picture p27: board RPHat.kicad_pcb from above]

Board: 2 copper layers, 65.5 x 56.9 mm, 6 parts (0 on the bottom side), 24 nets.

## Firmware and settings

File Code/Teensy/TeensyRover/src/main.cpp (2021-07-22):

#include <Arduino.h>

#define Resolution  12
#define PWMPinRightWheel     9
#define PWMPinLeftWheel     5

static float integerResolution = 4095; //2^Resolution-1
//static float dutyCycle = 0.2;

const byte numChars = 32;
char serialBuffer[8], SpeedBuffer[4];
bool newData = false;

int speedWheel0, speedWheel1, pwm_value;

void setupMotor()
{

    analogWrite(PWMPinRightWheel, (int) (0.24*integerResolution));
    analogWrite(PWMPinLeftWheel, (int) (0.24*integerResolution));
    delay(12000);
    analogWrite(PWMPinRightWheel, (int) (0.13*integerResolution));
    analogWrite(PWMPinLeftWheel, (int) (0.13*integerResolution));
    delay(10000);
}

void recvWithEndMarker() {
    static byte ndx = 0;
    char endMarker = '\n';
    char rc;

    // if (Serial.available() > 0) {
    while (Serial1.available() > 0 && !newData) {
        rc = Serial1.read();

        if (rc != endMarker) {
            serialBuffer[ndx] = rc;
            ndx++;
            if (ndx >= numChars) {
                ndx = numChars - 1;
            }
        }
        else {
            serialBuffer[ndx] = '\0'; // terminate the string
            ndx = 0;
            newData = true;
        }
    }
}

void showNewData() {
    if (newData) {
        Serial.print("This just in ... ");
        Serial.println(serialBuffer);
    }
}

int ConvertToPWM(const int pin, int speed)
{

    //0 = 0, 100 = 4095
    //We want 0 = 13, 100 = 24
    //(13/100)*4095 = 532
    //(24/100)*4095 = 983
    if(speed <= 100 && speed > 0) {
        pwm_value = 532+(speed*(983-532))/100;
        analogWrite(pin, pwm_value);
        return 1;
    } else if (speed == 0){
        //Turn off pwm if something is funky
        analogWrite(PWMPinRightWheel, 0);
        analogWrite(PWMPinLeftWheel, 0);
    }
    return 0;
}


//char buffer[3];

void setup() {
// write your initialization code here
    analogWriteFrequency(PWMPinRightWheel, 1000);
    analogWriteFrequency(PWMPinLeftWheel, 1000);
    analogWriteResolution(Resolution);

    Serial.begin(115200);

    Serial1.setRX(0);

    //Serial1.setTX(1);

    Serial1.begin(57600);
/*
    buffer[0] = '7';
    buffer[1] = '5';
    buffer[2] = '\n';
*/
    //setupMotor();

    //analogWrite(9, (int) (0.13*integerResolution));
}


void loop() {
// write your code here
/*
    Serial1.write((uint8_t*) buffer, sizeof(buffer));
    delay(200);
*/

recvWithEndMarker(); //MUNA EFTIR '\n'!!!!!
if(newData) {
    if (serialBuffer[0] == 's' && serialBuffer[4] == 'p' )
    {
        setupMotor();
    }
    else {
        showNewData();


        //speedWheel0 = (uint8_t) serialBuffer[0];
        //speedWheel1 = (uint8_t) serialBuffer[1];

        SpeedBuffer[0] = serialBuffer[0];
        SpeedBuffer[1] = serialBuffer[1];
        SpeedBuffer[2] = '\0';

        speedWheel0 = atoi(SpeedBuffer);


        SpeedBuffer[0] = serialBuffer[3];
        SpeedBuffer[1] = serialBuffer[4];

        speedWheel1 = atoi(SpeedBuffer);


        if (!ConvertToPWM(PWMPinRightWheel, speedWheel0)) {
            //Something Error


        }

        if (!ConvertToPWM(PWMPinLeftWheel, speedWheel1)) {
            //Something Error
        }
    }

        for (uint8_t n = 0; n < sizeof(serialBuffer); n++) {
            serialBuffer[n] = '0';
        }
    newData = false;
}

}

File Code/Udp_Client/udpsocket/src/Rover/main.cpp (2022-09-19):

#include "udpClientClass.h"
#include "circBuffer.h"
#include "iostream"
#include <cstdlib>

#include <thread>
#include <opencv2/opencv.hpp>

#include <wiringPi.h>
#include <wiringSerial.h>


using namespace std;


enum Command{
    SPEED = 's',
    TEXT = 't',
    CAMERA = 'c'
};

/*
 * Runs the system command for text to speech. USes the festival plugin.
 */

void Text2Speech(string message)
{
    message.erase(1,0);
    string command_string = "echo "+ message + " | festival --tts";
    system(command_string.c_str());
}

int FindChar(const char *arr, const char char2find)
{
    for (int index = 0; index < sizeof(arr); index++)
    {
        if (*(arr+index) == char2find)
        {
            return index;
        }
    }
    cout << "Character not found" << endl;
    return 1;
}
/*
 * Sends data over the UART to the Teensy. As of now, it only sends the speed array as the Teensy only controls the PWM to be sent to the ESC.
 * Will need to be updated once servos are added.
 */
void TransmitUARTThread(int fd, const char *sendBuffer)
{
    char UARTBuffer[8];

    int index = FindChar(sendBuffer, '.');
    if(index == -1)
    {
        return;
    }
    else
        for(int i = 0; i < index; i++) {
            UARTBuffer[i] = *(sendBuffer + index+i);
        }

            UARTBuffer[index+1] = '\n';
            UARTBuffer[index+2] = '\0';
            serialPrintf(fd, UARTBuffer);
}

void ReceiveUDPThread(udp_client_server::udp_client& Client, circBuffer<string>& mCircularBuffer){
    char recvBuffer[32];

    while(true) {
        Client.recv(recvBuffer, sizeof(recvBuffer));
        mCircularBuffer.put(string(recvBuffer));
    }
}

void TransmitUDPThread(udp_client_server::udp_client& Client){

}

udp_client_server::udp_client setupUDP(const string& IP, const int PORT)
{
    //int PORT = 8080;
    //const string IP = "127.0.0.1"; //localhost
    const string HelloMsg = "i am rover";
    char roleBuffer[64];

    udp_client_server::udp_client RoverClient(IP, PORT);

    RoverClient.send(HelloMsg.c_str(), HelloMsg.length());

    RoverClient.recv(roleBuffer, 64);

    cout << "Server : " << roleBuffer << endl;

    return RoverClient;
}

int setupUART(int baudrate, int &fd)
{
    if((fd = serialOpen("/dev/ttyS0",baudrate)) < 0) return 1;
    if(wiringPiSetup() < 0) return 1;
    return 0;
}
int main(){

    int fd;
    string Temp;
    Command recvCommand;
    circBuffer<string> commandBuffer(32);

    udp_client_server::udp_client RoverClient = setupUDP("xxx.xxx.xxx.xxx", 20001);

    setupUART(57600, fd);

    thread recvT(ReceiveUDPThread, ref(RoverClient), ref(commandBuffer));

    while(true) {
        Temp = commandBuffer.get();
        recvCommand = (Command) Temp.at(0);

        switch (recvCommand) {
            case SPEED: {
                thread uartT(TransmitUARTThread, fd, (Temp.c_str()));
            }
            case TEXT: {
                thread textT(Text2Speech, Temp);
            }
            case CAMERA: {
                //Here goes the camera servo implementation.
                break;
            }
            default:{
                cout << "Command " << recvCommand << " is not a valid command." << endl;
            }
        }
    }
}
/*
int main() {


        char sendBuffer[128];
        char UartBuffer[7];

        int speedRight = 0,speedLeft = 0, i = 0;
        int fd;

    udp_client_server::udp_client RoverClient = setupUDP("167.71.138.109", 20001);

    if (!setupUART(57600, fd)) return 1;


        for (int k = 0; k < sizeof(sendBuffer); k++)
        {
            sendBuffer[k] = '0';
        }
        char quickFix[4];

        for(;;){

            i = RoverClient.recv(sendBuffer, 128);
            sendBuffer[i] = '\0';
            //cout << "Server : " << sendBuffer << endl;
            if (sendBuffer[2] == 's') {
                quickFix[0] = sendBuffer[3];
                quickFix[1] = sendBuffer[4];
                quickFix[2] = '\0';

                speedRight = atoi(quickFix);

                quickFix[0] = sendBuffer[6];
                quickFix[1] = sendBuffer[7];

                speedLeft = atoi(quickFix);

                //cout << "Speed conversion : " << speedRight << ", " << speedLeft << endl;


                if ((speedRight <= 100 && speedRight >= 0) && (speedLeft <= 100 && speedLeft >= 0)) {

                    UartBuffer[0] = sendBuffer[3];
                    UartBuffer[1] = sendBuffer[4];
                    UartBuffer[2] = '.';
                    UartBuffer[3] = sendBuffer[6];
                    UartBuffer[4] = sendBuffer[7];
                    UartBuffer[5] = '\n';
                    UartBuffer[6] = '\0'; //Muna eftir þessu! serialPrintf gerir ráð fyrir '\0'
                    serialPrintf(fd, UartBuffer);

                } else {
                    cout << "Value is not valid. Please enter a number between 0 to 100" << endl;
                    speedRight = 0;
                    speedLeft = 0;
                }
            }
            else if (sendBuffer[2] == 't')
            {
                Text2Speech(sendBuffer+1);
            }
            RoverClient.send(sendBuffer, i);
        }

        serialClose(fd);
    }
*/

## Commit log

2021-02-03 organized the project. Started porting the code over to C++ due to better threading support.
2021-02-09 Delete Code/Raspberry directory
    Directory is useless now.
2021-05-01 Why cant I just learn github
    [Hall Effect Schematics.sch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]
2021-05-12 Working on the PCB
    [RPHat_V2.sch, Sensors.sch]
2021-05-12 Configured pinout for logic converter
    [RPHat_V2.sch, Sensors.sch]
2021-05-13 Started routing for the BMS
    [RPHat_V2.sch, Sensors.sch]
2021-05-15 Continued routing the pcb. Added current sensing sensor
    [RPHat_V2.sch, Sensors.sch]
2021-05-15 Schematic clean-up
    [Hall Effect Schematics.sch, RPHat_V2.sch, Sensors.sch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]
2021-05-19 Started routing PCB
    [Hall Effect Schematics.sch, RPHat_V2.sch, Sensors.sch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]
2021-05-22 Added footprints to all componetns
    [Hall Effect Schematics.sch, RPHat_V2.kicad_pcb, RPHat_V2.sch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]
2021-05-25 started pcb routing
    [EDI2CAP.CFG, RPHat_V2.kicad_pcb, Sensors.sch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]
2021-05-26 Continued working on the pcb
    [RPHat_V2.kicad_pcb, RPHat_V2.sch, Sensors.sch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]
2021-05-29 Never gonna give you up
    [RPHat_V2.kicad_pcb, Sensors.sch]
2021-05-30 working on pcb Ja!
    [RPHat_V2.kicad_pcb, Sensors.sch, Servos_Motors.sch]
2021-06-10 pcb update
    [RPHat_V2.kicad_pcb]
2021-06-11 Work, work, work
    [56_to_1_housing.3mf, RPHat_V2.kicad_pcb, RPHat_V2.sch]
2021-06-12 PCB done. only a few grounding vias left to add
    [RPHat_V2.kicad_pcb]
2021-06-14 retraced as well as added ground vias
    [RPHat_V2.kicad_pcb]
2021-06-19 Commit update
    [RPHat_V2-B_Cu.gbl, RPHat_V2-B_Mask.gbs, RPHat_V2-B_Paste.gbp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]
2021-07-22 Fixed linking issue and finished pcb
    [RPHat_V2.kicad_pcb, RPHat_V2.sch, Sensors.sch]
